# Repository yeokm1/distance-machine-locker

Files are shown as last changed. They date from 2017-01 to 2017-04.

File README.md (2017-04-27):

# Distance Machine Locker

A system that locks your computer the moment you move away from it. An Arduino-based hardware senses how far are you away from the computer and reports it to a host app on your machine. When a set threshold has been reached, the machine is locked.

If the device is forcefully detached from the PC while the app is in operation, the app will lock your machine and reconnect back once the device is attached again.

Only Mac OS is supported at this time.

## Demo media

(https://www.youtube.com/watch?v=mWyIHkdfHz4)  
Video of everything in action.

(https://www.youtube.com/watch?v=80zMLssycmM)  
Video of the talk I gave on this setup

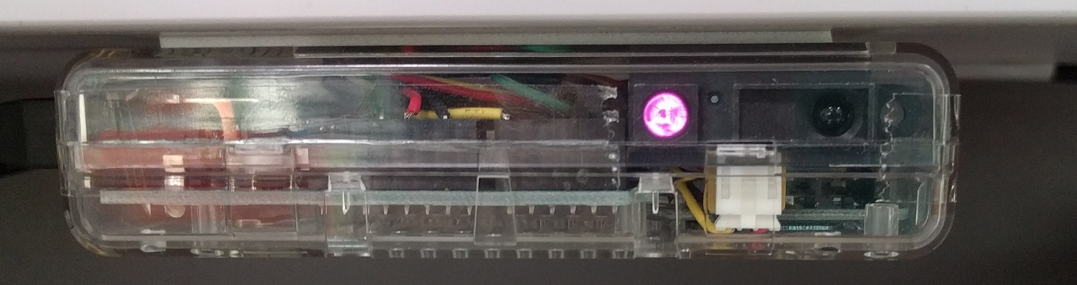
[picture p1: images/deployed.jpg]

My device deployed under my desk. The purple light coming from the sharp IR sensor cannot be seen with a naked eye but the camera can.

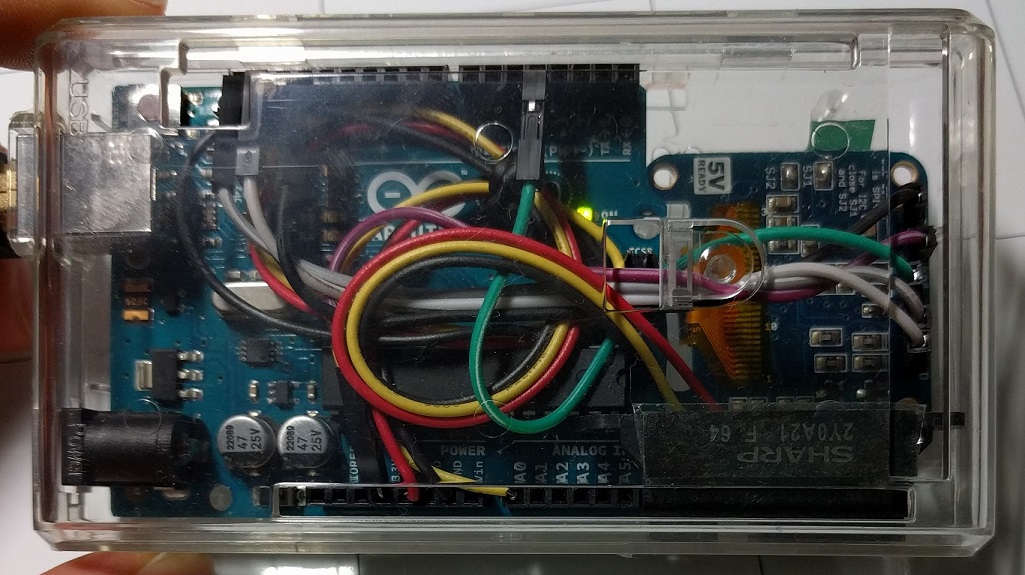
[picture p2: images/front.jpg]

Front view of device

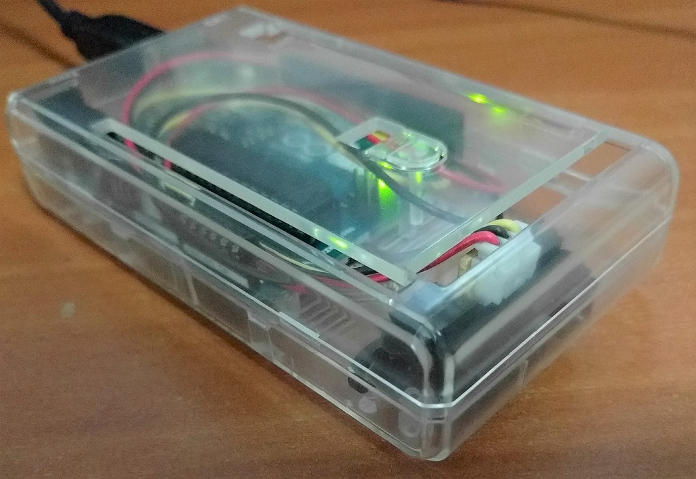
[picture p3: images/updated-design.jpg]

This is the "production" design that does not have the OLED screen to save costs. The sensor position is shifted to take advantage of the gap in the top cover to give the wire some allowance to bend.

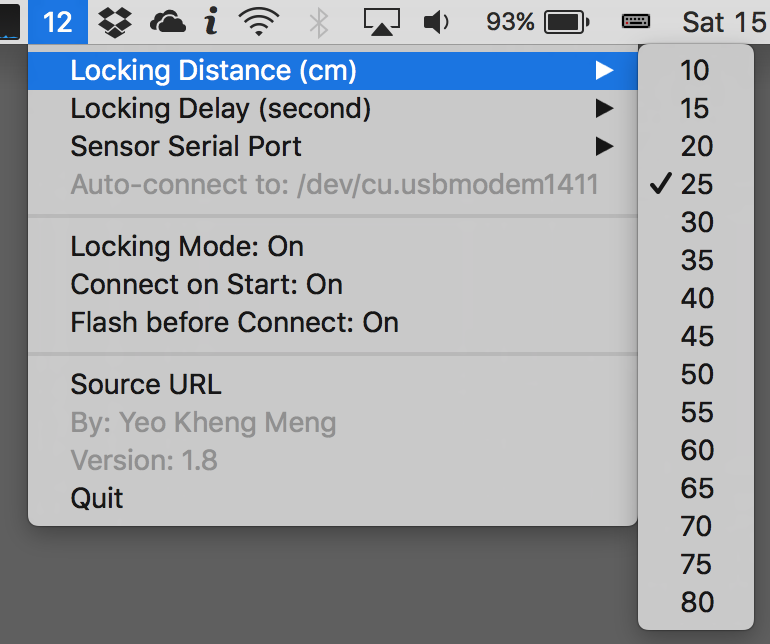
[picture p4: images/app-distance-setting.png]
  
Feature to customise the locking distance threshold.

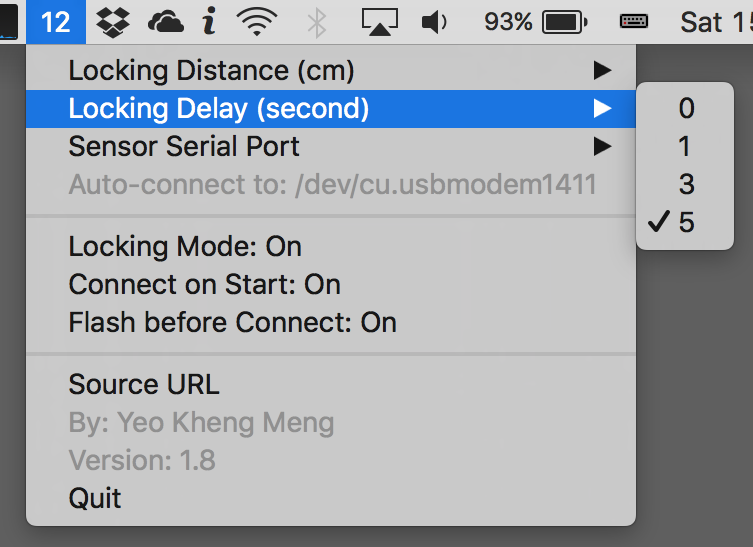
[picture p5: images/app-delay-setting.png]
  
Customise a delay before locking to let you have time to get back into range.

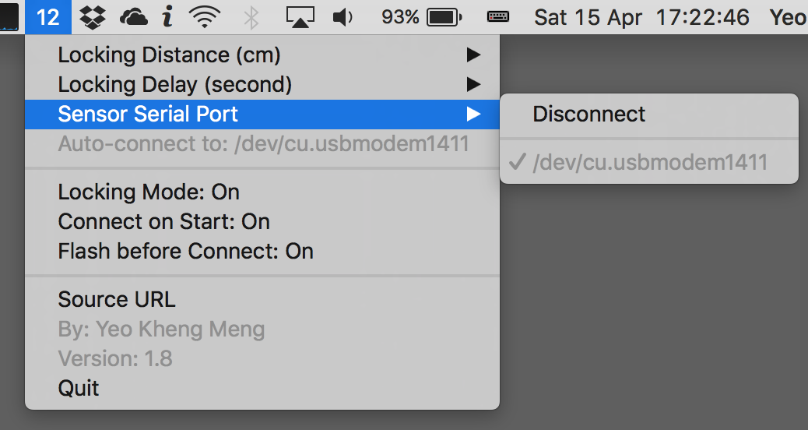
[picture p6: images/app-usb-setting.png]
  
Shows the currently connected USB Serial port as well as other ports if available.

## Features

1. Locks Mac on threshold reached
2. Shows live distance reading on menubar
3. Customisable threshold from 10cm to 80cm which is the effective range of the IR sensor
4. Choice to flash firmware before connection
5. Choice to auto connect to device if only one sensor is found
6. Locks machine if device is disconnected
7. Notifications to indicate flashing/connect/disconnect status
8. If locking mode is disabled for testing purposes, a red background is placed behind the distance text to alert the user of lack of security.
9. Auto reconnect back to device if it was forcefully disconnected previously. Auto-reconnection does not happen if you manually disconnect using the menu.
10. Adjustable delay to avoid unnecessary locking if the user can come back into range within a time window.

## Rough steps to quick start

1. Build the hardware, connect it to your Mac
2. Download and install the Arduino app into `/Applications`. The Arduino app is also used by my app to flash the firmware.
2. Use Arduino app to flash firmware or flash from command line. Replace path to `distance-machine-locker-arduino.hex` and serial port `/dev/ttyusbmodemX` with the exact ones. `/Applications/Arduino.app/Contents/Java/hardware/tools/avr/bin/avrdude -C /Applications/Arduino.app/Contents/Java/hardware/tools/avr/etc/avrdude.conf -p atmega328p -b 115200 -c arduino -U flash:w:distance-machine-locker-arduino.hex:i -P /dev/ttyusbmodemX`
3. Download from releases, Unzip and copy `Distance Mac Locker.app` into `/Applications`
4. Lock the system immediately when screensaver is enabled or display sleeps. System Preferences -> Security and Privacy -> Require password "immediately"
5. Start the app
6. Connect to the associated USB Serial port
7. Turn off locking mode and decide your threshold distance
8. Set your threshold distance and turn locking mode back on
9. Optionally turn on `Connect on Start` and `Flash before Connect`. Configure locking delay if you want.
10. Make app start on login by. System Preferences -> Users and Groups -> Login Items -> + app into list

## Documentation

Extra documentation is available in the readme files of the subdirectories.

1. [Hardware schematic and components](schematic/README.md)
2. [Arduino Code](distance-machine-locker-arduino/README.md)
3. [Swift Host Code](Distance%20Mac%20Locker/README.md)

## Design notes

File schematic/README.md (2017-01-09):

# Distance Machine Locker hardware

## Schematic

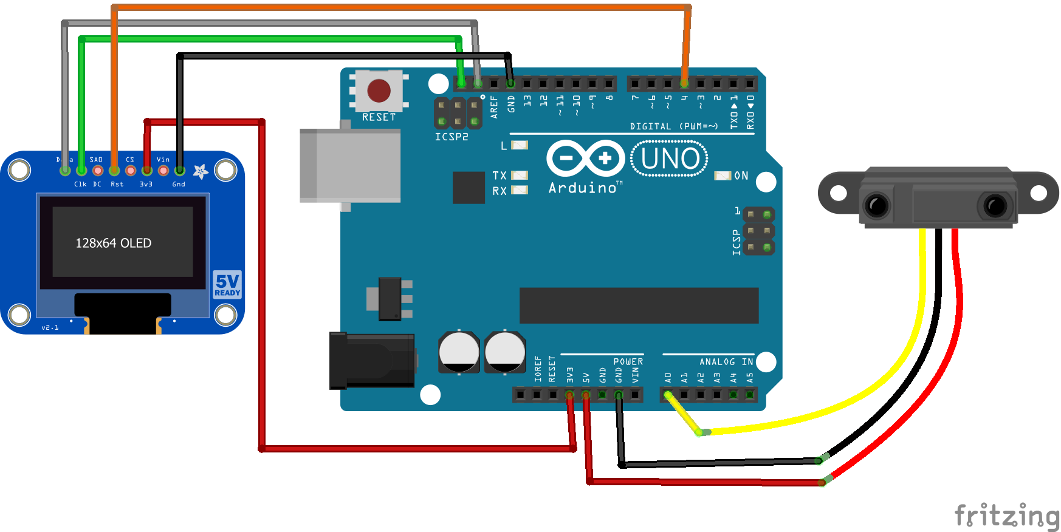
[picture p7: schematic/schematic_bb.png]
Screen


## Components

1. Arduino Uno R3
2. [Sharp GP2Y0A21YK IR sensor 10-80cm](http://www.sgbotic.com/index.php?dispatch=products.view&product_id=20)
3. [Arduino Mega 2560 R3 clear enclosure](http://www.sgbotic.com/index.php?dispatch=products.view&product_id=1602)
4. Standard Type-A to Type-B USB cable
5. [Adafruit Monochrome 1.3" 128x64 OLED](https://www.adafruit.com/product/938)

## Component comments

The use of a case meant for the larger Arduino is so we have extra space to accomodate the components.

OLED is optional in the operation of the device. It is just for my debugging of the sensor. I have tested the code to still work even without the OLED.

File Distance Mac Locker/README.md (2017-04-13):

# Distance Mac locker

This is the host app portion of the system. It receives distance data via a USB cable from the Arduino hardware. The distance data is compared to a provided threshold and the Mac is locked should the threshold be met.

App is written in Swift and is considered a Menubar App as lives in the OSX menubar and does not have a main Window.

## Setting up

1. Make sure you install the Arduino app into `/Applications` before you proceed

2. Download and install the latest Xcode which is version 8.3.1 at the time of writing

3. Open `Distance Mac Locker.xcodeproj`

4. If you have modified the Arduino code and regenerated the hex file, drag and drop the new hex file into the Xcode project before recompiling.

## Libraries and images used
1. Serial Port communication with the Arduino is handled with my [SwiftSerial](https://github.com/yeokm1/SwiftSerial) library. I'm unsure how to use Swift Package Manager with Xcode so I just dropped the code of the entire library in.
2. [Lock icon as app icon](https://www.iconfinder.com/icons/314694/lock_open_icon)

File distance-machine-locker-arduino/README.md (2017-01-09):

# Distance Machine Locker Arduino

This is the code that runs on the Arduino Uno that measures the distance with a Sharp IR sensor before transmitting it over to the host machine over the USB-Serial cable. Distance in centimetres is sent at a rate of 5 times a second.

## Setting up the Arduino IDE on the Mac

1. Download the [Arduino IDE](https://www.arduino.cc/en/Main/Software) which is version 1.8.0 at the time of writing.

2. Make sure to copy the `Arduino.app` to the `/Applications` directory as part of its internal binary `avrdude` will be used by the Swift host app.

3. Open the `distance-machine-locker-arduino.ino` file.

4. Click Sketch -> Include Library -> Manage Libraries

5. Search and install the libraries `Adafruit GFX Library` and `Adafruit SSD1306`. This step is optional if you don't intend to use the OLED. Just comment out the `#define USING_OLED TRUE` the line.

6. Connect the Arduino setup, select `Arduino/Genuino Uno` as the board and you can upload the firmware.

7. Since the host app has the option to reprogram the board, we should export the binary. Sketch -> Export compiled Binary. Choose the one without the bootloader and rename it as something like `distance-machine-locker-arduino.hex` so we can use it later.

## Included library
1. [SharpIR library](https://github.com/guillaume-rico/SharpIR)

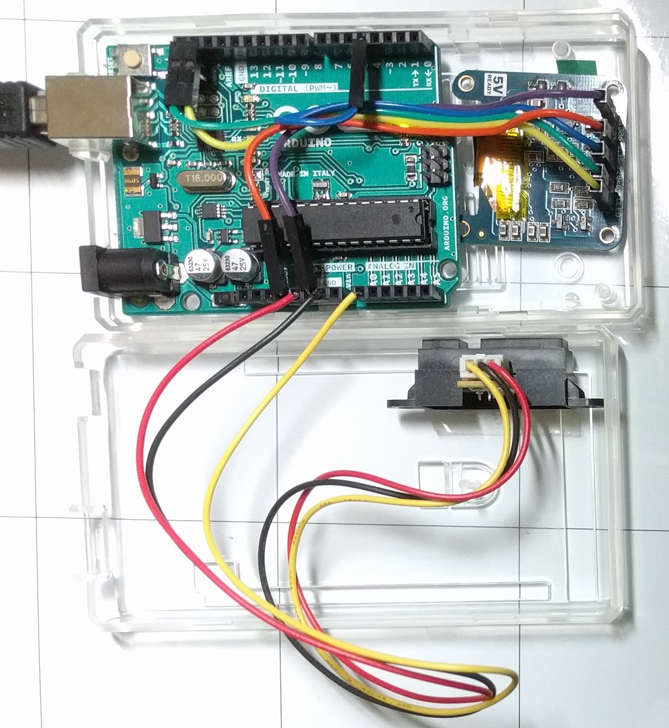
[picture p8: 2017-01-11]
images/internal.jpg

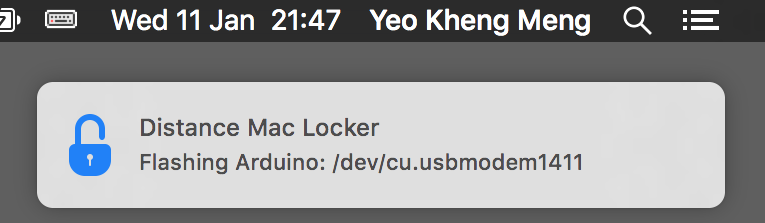
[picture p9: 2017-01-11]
images/app-noti-flashing.png

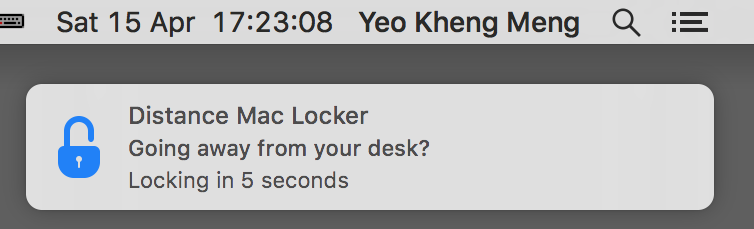
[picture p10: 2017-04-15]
images/app-noti-locking-delay.png

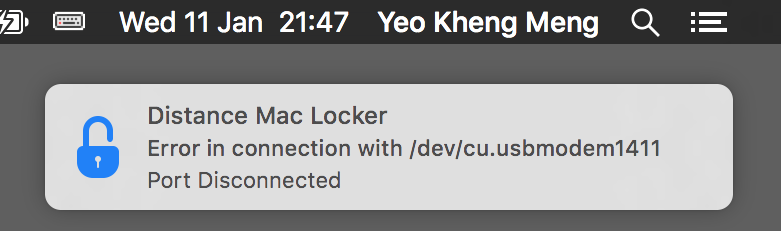
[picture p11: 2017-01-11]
images/app-noti-disconnect.png

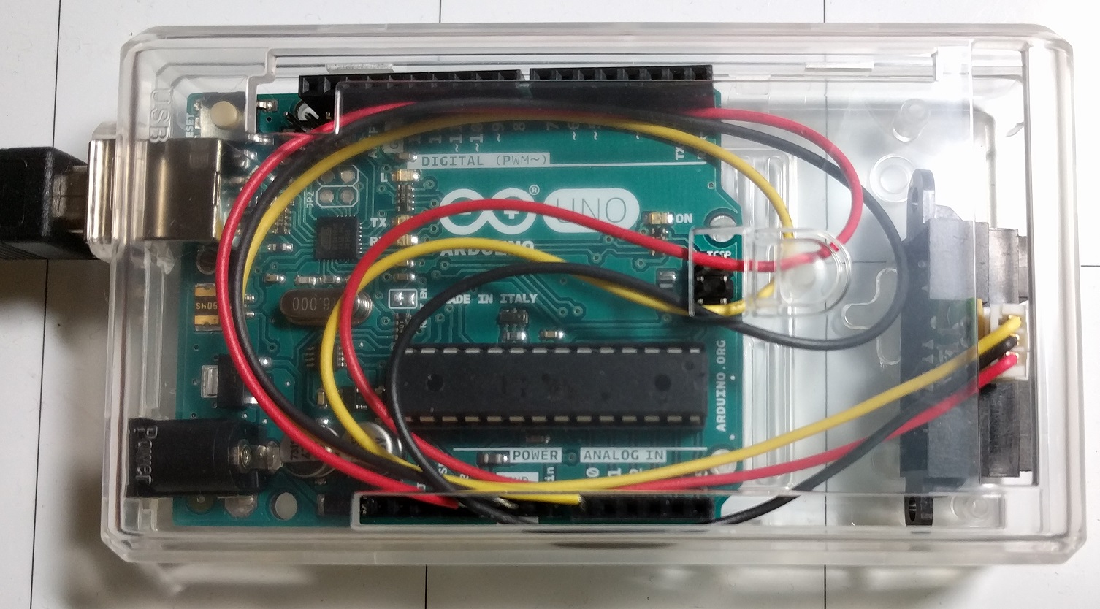
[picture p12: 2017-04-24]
images/front-updated.jpg

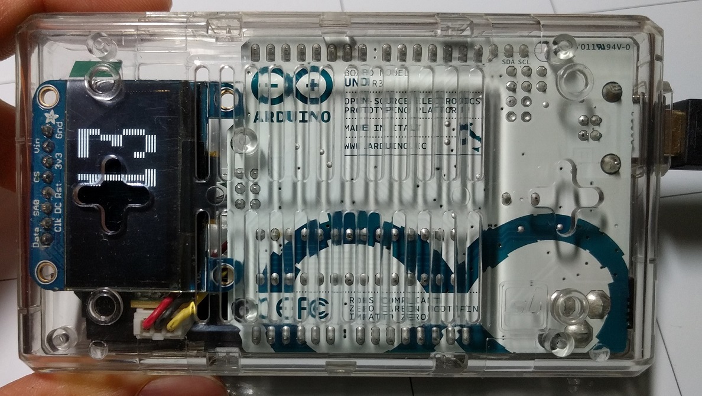
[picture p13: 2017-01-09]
images/back.jpg

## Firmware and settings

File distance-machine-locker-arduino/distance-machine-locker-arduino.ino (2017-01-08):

#define USING_OLED TRUE

#ifdef USING_OLED
  #include <SPI.h>
  #include <Wire.h>
  #include <Adafruit_GFX.h>
  #include <Adafruit_SSD1306.h>
  #define OLED_RESET 4
  Adafruit_SSD1306 display(OLED_RESET);
#endif

#include "SharpIR.h"

#define PIN_13 13

#define PIN_DISTANCE_SENSOR A0
#define model 1080 //1080 for GP2Y0A21Y

SharpIR SharpIR(PIN_DISTANCE_SENSOR, model);

void setup() {
  Serial.begin(9600);

  pinMode(PIN_13, OUTPUT);
  digitalWrite(PIN_13, LOW);

#ifdef USING_OLED
  display.begin(SSD1306_SWITCHCAPVCC, 0x3D);  // initialize with the I2C addr 0x3D (for the 128x64)
  display.setTextSize(4);
  display.setTextColor(WHITE);
  display.clearDisplay();
#endif
}

void loop() {
  delay(200);   

  int distance = SharpIR.distance();  // this returns the distance to the object you're measuring

#ifdef USING_OLED
  display.clearDisplay();
  display.setCursor(60,0);
  display.println(distance);
  display.display();
#endif

  Serial.println(distance);
}

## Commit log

2017-01-09 adjust port error logic. Show notification when machine is locked from device disconnected
2017-01-09 connections in fritzing
    [analog ir sensor.fzz, schematic.fzz]
2017-01-11 run port connection on another thread when clicked from the serial port menu
2017-01-11 update schematic shift ground wire of oled
    [schematic.fzz]
2017-03-25 added devices added to usb watcher
2017-03-25 able to connect back if the device is reconnected after an unplug
2017-03-25 auto connect to last forcefully disconnected device
